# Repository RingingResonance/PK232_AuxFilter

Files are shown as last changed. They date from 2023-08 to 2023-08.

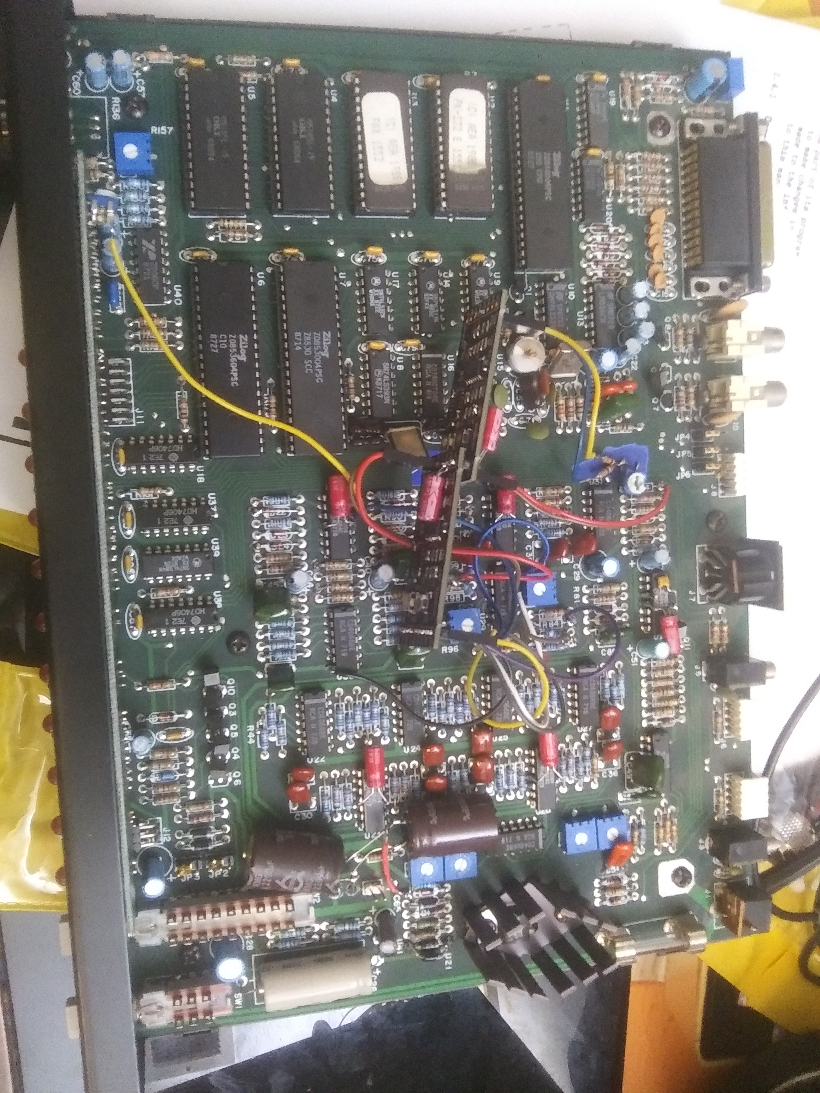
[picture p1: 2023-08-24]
20230823_195403.jpg

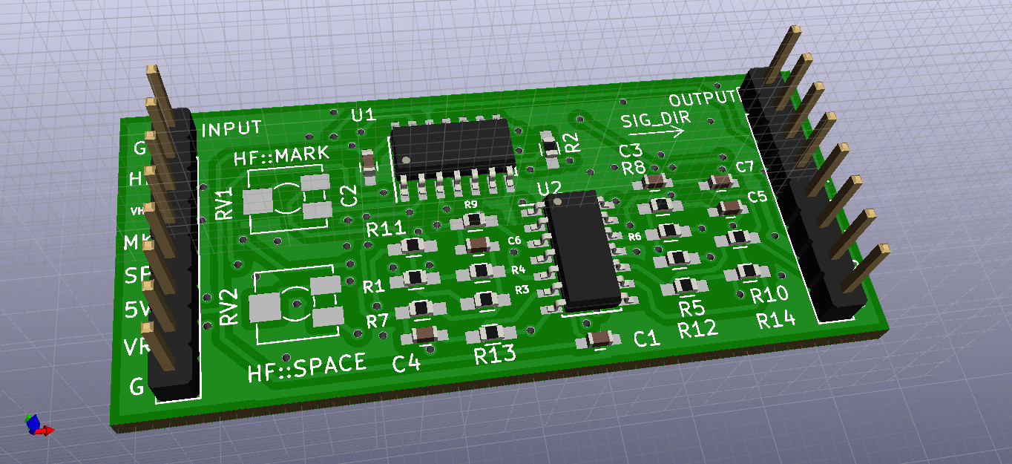
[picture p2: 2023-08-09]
AuxFilter.jpg

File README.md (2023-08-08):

# PK232_AuxFilter
An added filter stage for the PK232's packet modem descriminator based on the same circuit's existing filter design.

I don't have the best understanding of how this type of filter works so I copied that part of the schematic resistor-per-resistor
with the goal of helping the PK232 perform a little better when the incoming signal isn't full-quieting. Obviously this is for
models that don't have the DSP filter. This filter should be able to be used for other things by changing the resistor and capacitor
values to fit your needs. It would probably work on other TNC's.

Current resistor and capacitor values for Mark/Space:
VHF mode: 1200/2400 hz
HF mode: 2110/2310 hz

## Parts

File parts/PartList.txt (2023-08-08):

7: 0.01uF 0603 capacitor :: 399-17568-1-ND

2: 19.6K 0603 resistor :: 311-19.6KHRCT-ND

1: 8.2K 0603 resistor :: 311-8.2KGRCT-ND

2: 80.6K 0603 resistor :: 311-80.6KHRCT-ND

1: 20K 0603 resistor :: 13-RC0603FR-1320KLCT-ND

1: 22.1K 0603 resistor :: 311-22.1KHRCT-ND

1: 6.49K 0603 resistor :: 311-6.49KHRCT-ND

2: 10K 0603 resistor :: RNCP0603FTD10K0CT-ND

2: 23.2K 0603 resistor :: 311-23.2KHRCT-ND

2: 18.7K 0603 resistor :: 311-18.7KHRCT-ND

1: 5K 0603 resistor :: 3314J-502ECT-ND

1: 100K 0603 resistor :: 563-ST4ETA104CT-ND

1: Analog Switch SOIC 74HC4066D :: 1727-2811-1-ND

1: Quad Op-Amp SOIC AD8668ARZ :: 505-AD8668ARZ-ND

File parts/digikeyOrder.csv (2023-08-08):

Index | Quantity | Part Number | Manufacturer Part Number | Description | Customer Reference | Available | Backorder | Unit Price | Extended Price USD
1 | 10 | 399-17568-1-ND | C0603C103J5REC7411 | CAP CER SMD 0603 .01UF 5% X7R 50 |  | 10 | 0 | 0.13100 | 1.31
2 | 10 | 311-19.6KHRCT-ND | RC0603FR-0719K6L | RES 19.6K OHM 1% 1/10W 0603 |  | 10 | 0 | 0.01800 | 0.18
3 | 10 | 311-8.2KGRCT-ND | RC0603JR-078K2L | RES 8.2K OHM 5% 1/10W 0603 |  | 10 | 0 | 0.01400 | 0.14
4 | 10 | 311-80.6KHRCT-ND | RC0603FR-0780K6L | RES 80.6K OHM 1% 1/10W 0603 |  | 10 | 0 | 0.01800 | 0.18
5 | 10 | 13-RC0603FR-1320KLCT-ND | RC0603FR-1320KL | RES 20K OHM 1% 1/10W 0603 |  | 10 | 0 | 0.01800 | 0.18
6 | 10 | 311-22.1KHRCT-ND | RC0603FR-0722K1L | RES 22.1K OHM 1% 1/10W 0603 |  | 10 | 0 | 0.01800 | 0.18
7 | 10 | 311-6.49KHRCT-ND | RC0603FR-076K49L | RES 6.49K OHM 1% 1/10W 0603 |  | 10 | 0 | 0.01800 | 0.18
8 | 10 | RNCP0603FTD10K0CT-ND | RNCP0603FTD10K0 | RES 10K OHM 1% 1/8W 0603 |  | 10 | 0 | 0.05900 | 0.59
9 | 10 | 311-23.2KHRCT-ND | RC0603FR-0723K2L | RES 23.2K OHM 1% 1/10W 0603 |  | 10 | 0 | 0.01800 | 0.18
10 | 10 | 311-18.7KHRCT-ND | RC0603FR-0718K7L | RES 18.7K OHM 1% 1/10W 0603 |  | 10 | 0 | 0.01800 | 0.18
11 | 2 | 3314J-502ECT-ND | 3314J-1-502E | TRIMMER 5K OHM 0.25W J LEAD TOP |  | 2 | 0 | 1.83000 | 3.66
12 | 2 | 563-ST4ETA104CT-ND | ST4ETA104 | TRIMMER 100KOHM 0.25W J LEAD TOP |  | 2 | 0 | 1.80000 | 3.60
13 | 2 | 1727-2811-1-ND | 74HC4066D,653 | IC SWITCH SPST-NO X 4 95OHM 14SO |  | 2 | 0 | 0.45000 | 0.90
14 | 4 | 505-AD8668ARZ-ND | AD8668ARZ | IC OPAMP GP 4 CIRCUIT 14SOIC |  | 4 | 0 | 5.89000 | 23.56

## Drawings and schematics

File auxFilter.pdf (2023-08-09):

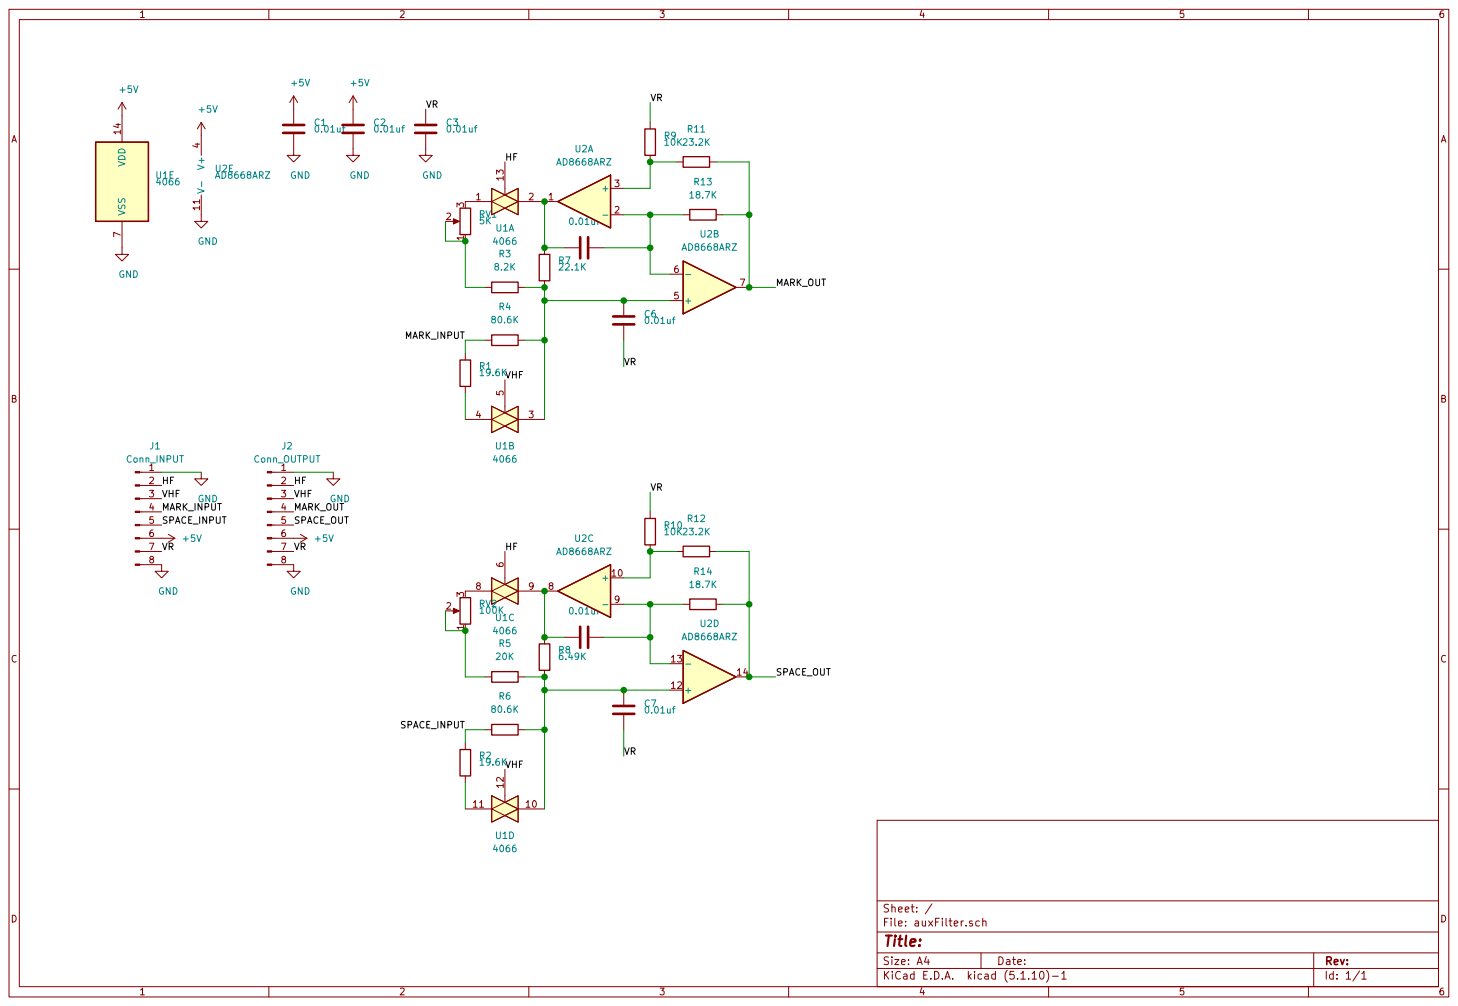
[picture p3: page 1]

Id: 1/1 Title: File: auxFilter.sch Sheet: / R10 10K GND

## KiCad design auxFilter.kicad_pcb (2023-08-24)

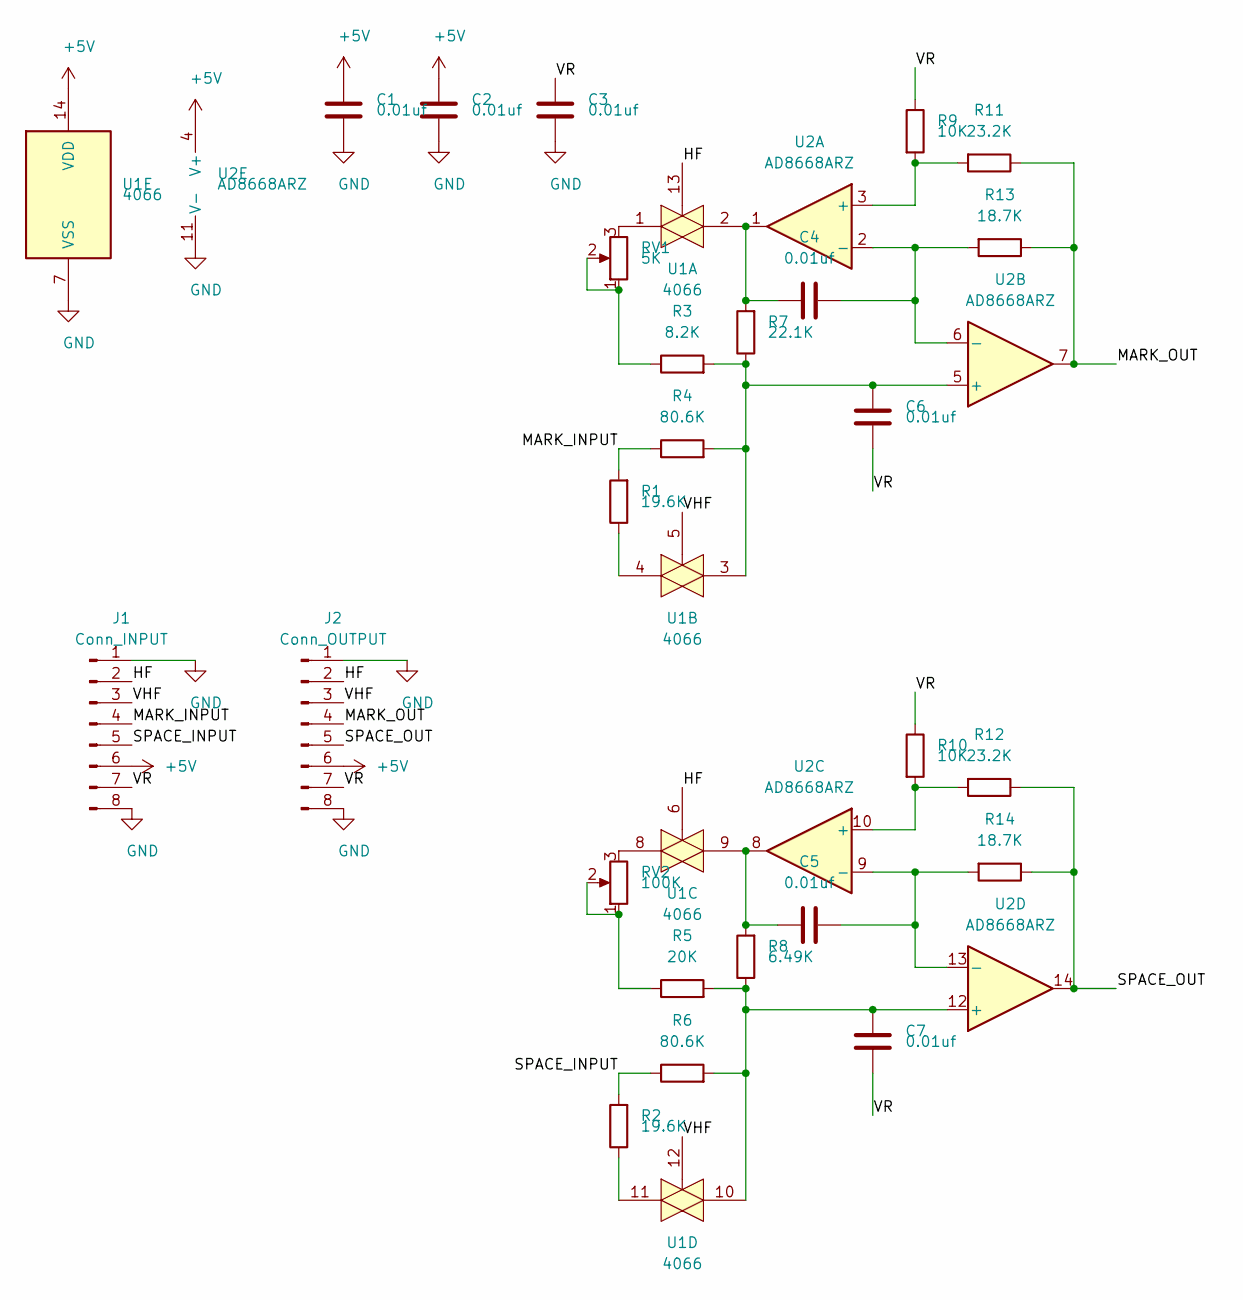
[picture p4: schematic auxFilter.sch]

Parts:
C1, C2, C3, C4, C5, C6, C7: 0.01uf; C_0603_HandSoldering; digikey 399-17568-1-ND
J1: Conn_INPUT; Pin_Header_Straight_1x08_Pitch2.54mm
J2: Conn_OUTPUT; Pin_Header_Straight_1x08_Pitch2.54mm
R1, R2: 19.6K; R_0603_HandSoldering; digikey 311-19.6KHRCT-ND
R3: 8.2K; R_0603_HandSoldering; digikey 311-8.2KGRCT-ND
R4, R6: 80.6K; R_0603_HandSoldering; digikey 311-80.6KHRCT-ND
R5: 20K; R_0603_HandSoldering; digikey 13-RC0603FR-1320KLCT-ND
R7: 22.1K; R_0603_HandSoldering; digikey 311-22.1KHRCT-ND
R8: 6.49K; R_0603_HandSoldering; digikey 311-6.49KHRCT-ND
R9, R10: 10K; R_0603_HandSoldering; digikey RNCP0603FTD10K0CT-ND
R11, R12: 23.2K; R_0603_HandSoldering; digikey 311-23.2KHRCT-ND
R13, R14: 18.7K; R_0603_HandSoldering; digikey 311-18.7KHRCT-ND
RV1: 5K; Potentiometer_Trimmer_Vishay_TS53YJ; digikey 3314J-502ECT-ND
RV2: 100K; Potentiometer_Trimmer_Vishay_TS53YJ; digikey 563-ST4ETA104CT-ND
U1: 4066; SOIC-14_3.9x8.7mm_Pitch1.27mm; digikey MC14066BDR2GOSCT-ND
U2: AD8668ARZ; SOIC-14_3.9x8.7mm_Pitch1.27mm; digikey 505-AD8668ARZ-ND

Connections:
+5V: C1.1, C2.1, J1.6, J2.6, U1.14 (VDD), U2.4 (V+)
/HF: J1.2, J2.2, U1.6, U1.13
/MARK_INPUT: J1.4, R1.2, R4.1
/MARK_OUT: J2.4, R11.1, R13.1, U2.7
/SPACE_INPUT: J1.5, R2.2, R6.1
/SPACE_OUT: J2.5, R12.1, R14.1, U2.14
/VHF: J1.3, J2.3, U1.5, U1.12
/VR: C3.1, C6.2, C7.2, J1.7, J2.7, R9.1, R10.1
GND: C1.2, C2.2, C3.2, J1.1, J1.8, J2.1, J2.8, U1.7 (VSS), U2.11 (V-)
unnamed: C4.1, R13.2, U2.2 (-), U2.6 (-)
unnamed: C4.2, R7.2, U1.2, U2.1
unnamed: C5.1, R14.2, U2.9 (-), U2.13 (-)
unnamed: C5.2, R8.2, U1.9, U2.8
unnamed: C6.1, R3.2, R4.2, R7.1, U1.3, U2.5 (+)
unnamed: C7.1, R5.2, R6.2, R8.1, U1.10, U2.12 (+)
unnamed: R1.1, U1.4
unnamed: R2.1, U1.11
unnamed: R3.1, RV1.1, RV1.2
unnamed: R5.1, RV2.1, RV2.2
unnamed: R10.2, R12.2, U2.10 (+)
unnamed: R9.2, R11.2, U2.3 (+)
unnamed: RV1.3, U1.1
unnamed: RV2.3, U1.8

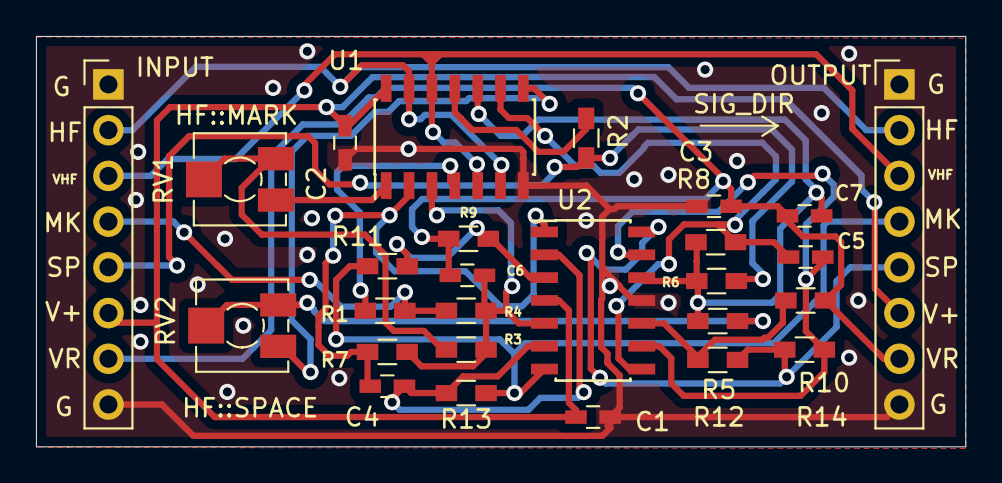
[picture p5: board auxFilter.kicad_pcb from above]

Board: 2 copper layers, 51.6 x 22.8 mm, 27 parts (0 on the bottom side), 23 nets.

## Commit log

2023-08-09 Added PDF schematic.
2023-08-09 Added board rendering.
2023-08-24 Added some new images. Changed analog switch part No to one that can handle more than 5v.
    [auxFilter-B_Cu.gbr, auxFilter-B_Mask.gbr, auxFilter-B_SilkS.gbr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]
